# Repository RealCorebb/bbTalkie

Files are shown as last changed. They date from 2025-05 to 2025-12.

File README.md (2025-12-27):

# bbTalkie [English](https://github.com/RealCorebb/bbTalkie/blob/main/README_EN.md "English")



## 不太一样的迷你对讲机

普通对讲机又大又笨，还得按键才能讲话。 有天骑行时，我想——能不能做一款便携、免按键的对讲机？ 于是我 DIY 了一款不太一样的对讲机，使用嵌入式神经网络🧠，能自动检测人声🗣️、识别关键词触发动画，其它对话也能转文字气泡显示，非常好玩。

😄[爱发电](https://afdian.com/a/kuruibb "爱发电")   
🐧QQ 群（仅供交流）：647186542  
🧵[Threads](https://www.threads.net/@coreoobb "@coreoobb") @coreoobb  
▶️ 本期视频(Video): [Youtube](https://youtu.be/v0QcsWsoYbw "Youtube") | [ Bilibili](https://www.bilibili.com/video/BV1qtBBBwEWv " Bilibili")

# 禁止搬运到 Gitee

Designed By Corebb With Love From bbRealm!

# 目录结构：

**CAD** 3D模型、DXF切割图纸  
**PCB** PCB 原理图、Gerber 制板文件、BOM 、坐标文件、EDA工程
**assets** 资源文件，如动画图像、音频、设计文件  
**esp-idf** 软件主程序，使用ESP-IDF V5.4.3版本，烧录到 ESP32 中  
**tests** 开发过程中用到的测试程序  
**tools** 软件部分开发辅助工具，如字体取模、图形转换、音频转换等  

# 如何使用 & FAQ：
需要用ESP32-S3 16MB Flash 8MB PSRAM的版本（只有这个才能用上Octal PSRAM，不然PSRAM速度跟不上会导致ESP-SR这套音频框架卡死）  
建议使用外置天线的版本：ESP32-S3-WROOM-1U-N16R8  
使用ESP-IDF开发环境编译并烧录  

# 参考资料：

开发框架  
[ESP-IDF快速入门](https://docs.espressif.com/projects/esp-idf/zh_CN/v5.4.3/esp32/get-started/index.html)
[ESP-SR](https://docs.espressif.com/projects/esp-sr/zh_CN/latest/esp32/getting_started/readme.html)

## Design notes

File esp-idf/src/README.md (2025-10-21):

#Antenna Test
Overair -55dbm | -80dbm
No.2 -55dbm | -76dbm
     -53dbM | -66dbM

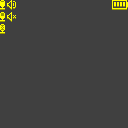
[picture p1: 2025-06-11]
IMG/UI_Concept.png

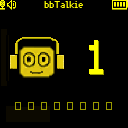
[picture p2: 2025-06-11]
IMG/bbTalkie_IDLE_Concept.gif

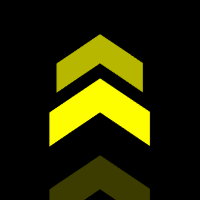
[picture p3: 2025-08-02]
IMG/go_straight.gif

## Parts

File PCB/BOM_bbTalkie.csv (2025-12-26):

Designator | Footprint | Value | Supplier Part | Manufacturer | Comment
C1,C5,C6,C12,C14 | C0603 | 1uF |  |  | 1uF
C2,C7,C8,C10 | C0603 | 0.1uF |  |  | 0.1uF
C3,C4,C9,C11 | C0603 | 10uF |  |  | 10uF
C13 | C0603 | 47uF |  |  | 47uF
C15 | C0603 | 22uF |  |  | 22uF
CN1,CN2 | CONN-SMD_2P-P1.00_SM02B-SRSS-TB-LF-SN |  | C160402 | JST | SM02B-SRSS-TB(LF)(SN)
D1 | SOD-323_L1.8-W1.3-LS2.5-RD |  | C22624 | CJ(江苏长电/长晶) | B5819WS
L1 | IND-SMD_L2.5-W2.0_SWPA252012S | 10uH | C37428 | Sunlord(顺络) | 10uH
L2 | IND-SMD_L2.0-W1.6-B | 1uH | C5832342 | cjiang(长江微电) | 1uH
LED1 | LED-SMD_WS2812B-4020 |  | C965557 | worldsemi | WS2812B-4020
R1,R3 | R0603 | 100K |  |  | 100K
R2 | R0603 | 390K |  |  | 390K
R4,R10,R11 | R0603 | 5.1K |  |  | 5.1K
R5 | R0603 | 10K |  |  | 10K
R6 | R0603 | 1.8K |  |  | 1.8K
R7,R8,R12 | R0603 | 511K |  |  | 511K
R9 | R0603 | 91K |  |  | 91K
SW1 | SW-SMD_TS24CA |  | C393942 | SHOU HAN(首韩) | TS24CA
U1 | WIRELM-SMD_ESP32-S3-WROOM-1 |  | C2913202 | ESPRESSIF(乐鑫) | ESP32-S3-WROOM-1-N16R8
U2 | MIC-SMD_6P-L3.5-W2.7-P0.90-BL |  | C5656610 | TDK InvenSense(应美盛) | ICS-43434
U3 | TQFN-16_L3.0-W3.0-P0.50-BL-EP1.5 |  | C910544 | ADI(亚德诺)/MAXIM(美信) | MAX98357AETE+T
U4 | SOT23-5@1 |  |  |  | FAN5331SX
U5 | SOT-583-8_L2.1-W1.6-P0.50-LS1.6-BL |  | C3235557 | TI(德州仪器) | TPS2116DRLR
U6 | SC-70-6_L2.2-W1.3-P0.65-LS2.1-BR |  | C2149796 | TI(德州仪器) | TPS22919DCKR
U7 | SOT-23-6_L2.9-W1.6-P0.95-LS2.8-BR |  | C82121 | MICRONE(南京微盟) | ME4055AM6G-N
U8 | SOT-583-8_L2.1-W1.2-P0.50-LS1.6-BL |  | C5219190 | TI(德州仪器) | TPS631000DRLR
USB1 | USB-C-SMD_KH-TYPE-C-16P |  | C709357 | kinghelm(金航标) | KH-TYPE-C-16P
X1 | OLED_1.5IN_128X128MONO |  |  |  | OLED_1.5_128X128_MONO

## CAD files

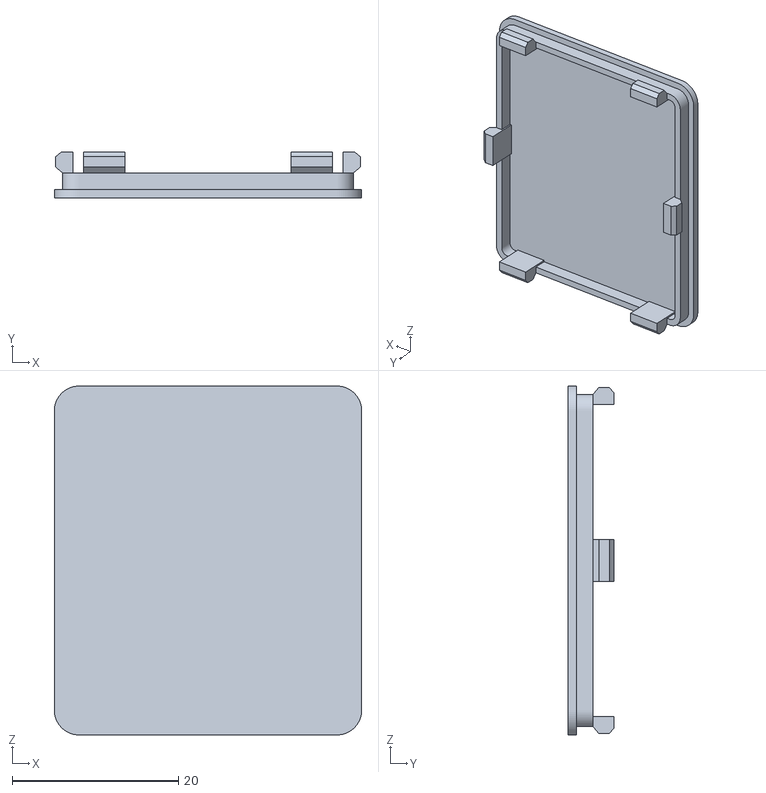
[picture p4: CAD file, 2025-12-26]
CAD/Bottom.stl
37.0 x 5.50 x 42.0

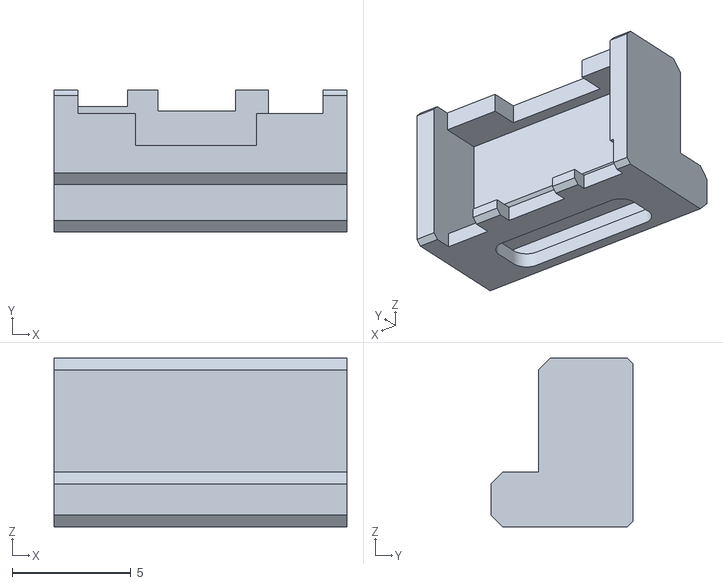
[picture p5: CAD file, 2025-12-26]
CAD/led_case.stl
12.3 x 6.00 x 7.10

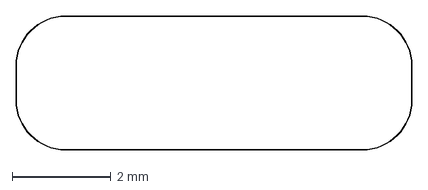
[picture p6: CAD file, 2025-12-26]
CAD/led_pmma.dxf
8.00 x 2.70 mm

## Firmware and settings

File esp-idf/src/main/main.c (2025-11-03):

/*
   This example code is in the Public Domain (or CC0 licensed, at your option.)

   Unless required by applicable law or agreed to in writing, this
   software is distributed on an "AS IS" BASIS, WITHOUT WARRANTIES OR
   CONDITIONS OF ANY KIND, either express or implied.
*/
#include <stdio.h>
#include <stdint.h>
#include <stdlib.h>
#include "freertos/FreeRTOS.h"
#include "freertos/queue.h"
#include "freertos/task.h"
#include "esp_wn_iface.h"
#include "esp_wn_models.h"
#include "esp_vadn_models.h"
#include "esp_afe_sr_models.h"
#include "esp_mn_iface.h"
#include "esp_mn_models.h"
#include "esp_board_init.h"
#include "model_path.h"
#include <math.h> // Add this for sin() function
#include <string.h>
#include "driver/gpio.h"
#include "include/sound.h"
#include "esp_audio_enc.h"
#include "esp_audio_enc_reg.h"
#include "esp_audio_enc_default.h"
#include "esp_audio_dec_default.h"
#include "esp_audio_dec.h"
#include "esp_adpcm_enc.h"
#include "esp_adpcm_dec.h"
#include <sys/socket.h>
#include <netinet/in.h>
#include <arpa/inet.h>

#include "esp_system.h"
#include "esp_now.h"
#include "esp_wifi.h"
#include "esp_timer.h"
#include "esp_event.h"
#include "esp_log.h"
#include "nvs_flash.h"

#include "lwip/err.h"
#include "lwip/sys.h"

#include "freertos/stream_buffer.h"

#include "esp32-spi-ssd1327.h"
#include <inttypes.h>
#include "driver/spi_master.h"
#include "include/images/logo.h"
#include "include/images/battery.h"
#include "include/images/mic.h"
#include "include/images/volume.h"
#include "include/images/home.h"
#include "include/images/custom.h"

#include "include/animation.h"
#include "include/command_map.h"

#include "include/fonts/fusion_pixel.h"
#include "include/fonts/fusion_pixel_30.h"

#include "driver/adc.h"
#include "soc/adc_channel.h"

#include "include/agc.h"
#include "include/led.h"
#include "esp_sleep.h"
#include "driver/rtc_io.h"
#include "iot_button.h"
#include "button_gpio.h"

#define SAMPLE_RATE 16000
#define BIT_DEPTH 16
#define ENCODED_BUF_SIZE 10240
#define PLAY_RING_BUFFER_SIZE 8192
#define PLAY_CHUNK_SIZE 2048
#define ESP_NOW_PACKET_SIZE 512

#define SPI_MOSI_PIN_NUM 14
#define SPI_SCK_PIN_NUM 13
#define SPI_CS_PIN_NUM 10
#define DC_PIN_NUM 12
#define RST_PIN_NUM 11
#define SPI_HOST_TAG SPI2_HOST

#define GPIO_WAKEUP_1 GPIO_NUM_4 // Charger CHRG
#define GPIO_WAKEUP_2 GPIO_NUM_8 // Button
#define GPIO_WAKEUP_3 GPIO_NUM_5 // Charger STDBY

// Button configuration
#define BUTTON_GPIO 8           // Boot button on most ESP32 boards
#define BUTTON_ACTIVE_LEVEL 0   // Active low (pressed = 0)
#define LONG_PRESS_TIME_MS 2000 // 2 seconds for long press

#define PING_MAGIC "PING"
#define PING_MAGIC_LEN 4
#define MAX_MAC_TRACK 9
#define MAC_TIMEOUT_MS 20000
int macCount = 1;
int lastMacCount = 0;
spi_oled_animation_t *anim_currentCommand = NULL;

typedef struct
{
    uint8_t mac[ESP_NOW_ETH_ALEN]; // 6 bytes
    int64_t last_seen_ms;          // Timestamp in ms
    bool valid;
} mac_track_entry_t;


#define ADPCM_FRAME_SIZE 505  // 每帧样本数
#define ADPCM_FRAME_BYTES (ADPCM_FRAME_SIZE * sizeof(int16_t))

// 编码缓冲区结构
typedef struct {
    int16_t buffer[ADPCM_FRAME_SIZE];
    size_t current_samples;  // 当前缓冲区中的样本数
} adpcm_encode_buffer_t;

adpcm_encode_buffer_t encode_buffer;

static mac_track_entry_t mac_track_list[MAX_MAC_TRACK];

const variable_font_t font_10 = {
    .height = 10,
    .widths = font_10_widths,
    .offsets = font_10_offsets,
    .data = font_10_data};

const variable_font_t font_30 = {
    .height = 30,
    .widths = font_30_widths,
    .offsets = font_30_offsets,
    .data = font_30_data};

static esp_afe_sr_iface_t *afe_handle = NULL;
srmodel_list_t *models = NULL;
StreamBufferHandle_t play_stream_buf;
static QueueHandle_t s_recv_queue = NULL;
static uint8_t broadcast_mac[ESP_NOW_ETH_ALEN] = {0xFF, 0xFF, 0xFF, 0xFF, 0xFF, 0xFF}; // Broadcast MAC address (all ones)
volatile bool is_receiving = false;
volatile bool is_speaking = false;
bool isShutdown = false;
bool isMicOff = false;
bool isMute = false;
bool is_command = false;
int state = 0; // 0: idle, 1: speaking, 2: receiving, 3: command
int lastState = -1;
static button_handle_t btn = NULL;
static bool button_initialized = false;
static const char *TAG = "bbTalkie";
spi_device_handle_t oled_dev_handle;
struct spi_ssd1327 spi_ssd1327 = {
    .dc_pin_num = DC_PIN_NUM,
    .rst_pin_num = RST_PIN_NUM,
    .spi_handle = &oled_dev_handle,
};
SemaphoreHandle_t spi_mutex;

// AGC playback
// Initialize AGC
agc_t agc_custom = {
    .current_gain = 1.0f,
    .target_rms = TARGET_RMS,
    .attack_rate = AGC_ATTACK,
    .release_rate = AGC_RELEASE
};

// Calculate RMS of audio buffer
float calculate_rms(int16_t* buffer, size_t samples) {
    float sum = 0.0f;
    for (size_t i = 0; i < samples; i++) {
        float sample = (float)buffer[i];
        sum += sample * sample;
    }
    return sqrtf(sum / samples);
}

// Apply AGC to audio buffer
void apply_agc(int16_t* buffer, size_t samples, agc_t* agc) {
    // Calculate current RMS level
    float current_rms = calculate_rms(buffer, samples);
    
    // Avoid division by zero
    if (current_rms < 1.0f) current_rms = 1.0f;
    
    // Calculate desired gain
    float desired_gain = agc->target_rms / current_rms;
    
    // Apply attack/release smoothing
    float rate = (desired_gain < agc->current_gain) ? agc->attack_rate : agc->release_rate;
    agc->current_gain += rate * (desired_gain - agc->current_gain);
    
    // Clamp gain to reasonable limits
    if (agc->current_gain < MIN_GAIN) agc->current_gain = MIN_GAIN;
    if (agc->current_gain > MAX_GAIN) agc->current_gain = MAX_GAIN;
    
    // Apply gain to all samples
    for (size_t i = 0; i < samples; i++) {
        float sample = (float)buffer[i] * agc->current_gain;
        
        // Clamp to prevent overflow
        if (sample > 32767.0f) sample = 32767.0f;
        if (sample < -32768.0f) sample = -32768.0f;
        
        buffer[i] = (int16_t)sample;
    }
}

// Structure to hold received data
typedef struct
{
    uint8_t data[ESP_NOW_MAX_DATA_LEN_V2];
    size_t data_len;
} esp_now_recv_data_t;

// Callback function called when data is sent
static void esp_now_send_cb(const uint8_t *mac_addr, esp_now_send_status_t status)
{
    if (status == ESP_NOW_SEND_SUCCESS)
    {
        // ESP_LOGI(TAG, "ESP-NOW data sent successfully");
    }
    else
    {
        ESP_LOGW(TAG, "ESP-NOW data send failed");
    }
}

void send_data_esp_now(const uint8_t *data, size_t len)
{
    size_t offset = 0;

    while (offset < len)
    {
        size_t chunk_size = len - offset > ESP_NOW_PACKET_SIZE ? ESP_NOW_PACKET_SIZE : len - offset;

        esp_err_t ret = esp_now_send(broadcast_mac, data + offset, chunk_size);
        if (ret != ESP_OK)
        {
            ESP_LOGE(TAG, "ESP-NOW send failed at offset %zu: %s", offset, esp_err_to_name(ret));
        }
        else
        {
            // ESP_LOGI(TAG, "Sent %zu bytes of data via ESP-NOW (offset %zu)", chunk_size, offset);
        }

        offset += chunk_size;
        vTaskDelay(pdMS_TO_TICKS(16));
    }
}

// Get received data (non-blocking)
bool get_esp_now_data(esp_now_recv_data_t *recv_data)
{
    if (s_recv_queue == NULL || recv_data == NULL)
    {
        return false;
    }

    return (xQueueReceive(s_recv_queue, recv_data, 0) == pdTRUE);
}

// Fade in drawText
void fade_in_drawCount(void *arg)
{
    const char *input_text = (const char *)arg;
    if (input_text == NULL || strlen(input_text) == 0)
    {
        printf("Invalid text\n");
        vTaskDelete(NULL);
        return;
    }
    for (int i = 0; i < 15; i++)
    {
        if (state == 0)
        {
            spi_oled_drawText(&spi_ssd1327, 86, 46, &font_30, i / 2, input_text, 0);
            spi_oled_drawText(&spi_ssd1327, 85, 45, &font_30, i, input_text, 0);
        }
        else
        {
            vTaskDelete(NULL);
        }
        vTaskDelay(pdMS_TO_TICKS(1000 / 15));
    }
    vTaskDelete(NULL);
}

// Animation task function
static void animation_task(void *pvParameters)
{
    spi_oled_animation_t *anim = (spi_oled_animation_t *)pvParameters;
    if (anim == NULL)
    {
        // Handle error - invalid key
        printf("Invalid animation parameters\n");
        vTaskDelete(NULL);
        return;
    }
    int current_frame = 0;
    uint8_t bytes_per_row = (anim->width + 1) / 2; // 4bpp packing
    while ((anim->stop_frame == -1 && anim->is_playing == true) ||
           (anim->stop_frame != -1 && (anim->is_playing == true || current_frame != anim->stop_frame)))
    {
        if (anim->stop_frame == -1 && anim->is_playing == false)
        {
            break;
        }
        if (anim->stop_frame != -1 && anim->is_playing == false && (state == 3 || current_frame == anim->stop_frame))
            break; // Force break when state is 3
        // Calculate frame data offset
        const uint8_t *frame_data = anim->animation_data +
                                    (current_frame * anim->height * bytes_per_row);

        // Lock SPI access
        xSemaphoreTake(spi_mutex, portMAX_DELAY);

        // Draw current frame
        spi_oled_drawImage(&spi_ssd1327,
                           anim->x, anim->y,
                           anim->width, anim->height,
                           frame_data, SSD1327_GS_15);

        // Release SPI access
        xSemaphoreGive(spi_mutex);

        // Move to next frame
        if (anim->reverse == true)
        {
            current_frame--;
        }
        else
            current_frame++;
        if (current_frame >= anim->frame_count)
        {
            current_frame = 0;
        }
        else if (current_frame < 0)
        {
            current_frame = anim->frame_count - 1;
        }

        vTaskDelay(pdMS_TO_TICKS(anim->frame_delay_ms));
    }
    vTaskDelete(NULL);
}

void stopAllAnimation()
{
    anim_waveBar.is_playing = false;
    anim.is_playing = false;
    anim_speaking.is_playing = false;
    anim_receiving.is_playing = false;
    anim_idleWaveBar.is_playing = false;
    anim_idleBar.is_playing = false;
    anim_podcast.is_playing = false;
    anim_speaker.is_playing = false;
     if (anim_currentCommand != NULL)
                anim_currentCommand->is_playing = false;
}

void bubble_text_task(void *arg)
{
    const char *input_text = (const char *)arg;
    if (input_text == NULL || strlen(input_text) == 0)
    {
        printf("Invalid text for bubble task\n");
        vTaskDelete(NULL);
        return;
    }

    // Create a local copy to prevent corruption
    char text[64]; // Adjust size as needed
    strncpy(text, input_text, sizeof(text) - 1);
    text[sizeof(text) - 1] = '\0';

    for (int i = -6; i < 0; i++)
    {
        spi_oled_drawImage(&spi_ssd1327, 17, i, 93, 11, (const uint8_t *)text_bubble, SSD1327_GS_15);
        spi_oled_drawText(&spi_ssd1327, 18, i, &font_10, SSD1327_GS_1, text, 86);
        vTaskDelay(pdMS_TO_TICKS(1000 / 15));
    }
    vTaskDelete(NULL);
}

// ESP-NOW receive callback
static void esp_now_recv_cb(const esp_now_recv_info_t *recv_info, const uint8_t *data, int data_len)
{
    if (recv_info == NULL || data == NULL || data_len <= 0)
    {
        return;
    }

    // Log reception
    
    ESP_ERROR_CHECK(esp_wifi_connectionless_module_set_wake_interval(0));
    ESP_LOGI(TAG, "Received %d bytes, RSSI: %d dBm", data_len, recv_info->rx_ctrl->rssi);

    if (data_len == PING_MAGIC_LEN && memcmp(data, PING_MAGIC, PING_MAGIC_LEN) == 0) // PING MSG
    {
        int64_t now = esp_timer_get_time() / 1000; // ms
        bool found = false;
        ESP_LOGI(TAG, "Received PING from %02x:%02x:%02x:%02x:%02x:%02x",
                 recv_info->src_addr[0], recv_info->src_addr[1],
                 recv_info->src_addr[2], recv_info->src_addr[3],
                 recv_info->src_addr[4], recv_info->src_addr[5]);
        for (int i = 0; i < MAX_MAC_TRACK; ++i)
        {
            if (mac_track_list[i].valid &&
                memcmp(mac_track_list[i].mac, recv_info->src_addr, ESP_NOW_ETH_ALEN) == 0)
            {
                mac_track_list[i].last_seen_ms = now;
                found = true;
                break;
            }
        }

        if (!found)
        {
            for (int i = 0; i < MAX_MAC_TRACK; ++i)
            {
                if (!mac_track_list[i].valid)
                {
                    memcpy(mac_track_list[i].mac, recv_info->src_addr, ESP_NOW_ETH_ALEN);
                    mac_track_list[i].last_seen_ms = now;
                    mac_track_list[i].valid = true;
                    ESP_LOGI(TAG, "Added MAC");
                    macCount += 1;
                    break;
                }
            }
        }
    }
    // CMD: prefix handling
    else if (data_len >= 4 && memcmp(data, "CMD:", 4) == 0)
    {
        if (data_len >= 5)
        {
            // Extract the command parameter after "CMD:"
            char cmd_param[32]; // Adjust size as needed
            int param_len = data_len - 4;
            if (param_len >= sizeof(cmd_param))
            {
                param_len = sizeof(cmd_param) - 1;
            }
            memcpy(cmd_param, data + 4, param_len);
            cmd_param[param_len] = '\0';

            // Convert to integer and handle animation
            int cmd_value = atoi(cmd_param);
            ESP_LOGI(TAG, "Processed CMD: %d", cmd_value);

            // Handle animation for received command
            printf("Playing animation for received command_id: %d\n", cmd_value);
            if (anim_currentCommand != NULL)
                anim_currentCommand->is_playing = false;
            anim_currentCommand = get_animation_by_key(cmd_value);
            lastState = -1;
            is_command = true;
        }
    }
    // MSG: prefix handling
    else if (data_len >= 4 && memcmp(data, "MSG:", 4) == 0)
    {
        if (data_len >= 5)
        {
            // Extract the message content after "MSG:"
            char msg_content[ESP_NOW_MAX_DATA_LEN_V2]; // Adjust size as needed
            int content_len = data_len - 4;
            if (content_len >= sizeof(msg_content))
            {
                content_len = sizeof(msg_content) - 1;
            }
            memcpy(msg_content, data + 4, content_len);
            msg_content[content_len] = '\0';
            ESP_LOGI(TAG, "Processed MSG: %s", msg_content);

            // Create bubble text task for received message
            char *msg_copy = malloc(strlen(msg_content) + 1);
            if (msg_copy != NULL)
            {
                strcpy(msg_copy, msg_content);
                xTaskCreate(bubble_text_task, "bubbleText", 4096, msg_copy, 5, NULL);
                ESP_LOGI(TAG, "Created bubble_text_task for received message: %s", msg_content);
            }
            else
            {
                ESP_LOGE(TAG, "Failed to allocate memory for bubble text message");
            }
        }
    }
    // Others MSG, Store in queue if available
    else if (s_recv_queue != NULL)
    {
        is_receiving = true;
        esp_now_recv_data_t recv_data;

        // Copy data (with size check)
        size_t copy_len = (data_len > ESP_NOW_MAX_DATA_LEN_V2) ? ESP_NOW_MAX_DATA_LEN_V2 : data_len;
        memcpy(recv_data.data, data, copy_len);
        recv_data.data_len = copy_len;

        // Send to queue, don't block if full
        xQueueSend(s_recv_queue, &recv_data, 0);
    }
}

// Initialize ESP-NOW
bool init_esp_now()
{
    // Initialize WiFi
    ESP_ERROR_CHECK(esp_netif_init());
    ESP_ERROR_CHECK(esp_event_loop_create_default());
    wifi_init_config_t cfg = WIFI_INIT_CONFIG_DEFAULT();
    esp_err_t ret = esp_wifi_init(&cfg);
    if (ret != ESP_OK)
    {
        ESP_LOGE(TAG, "WiFi init failed: %s", esp_err_to_name(ret));
        return false;
    }
    
    // Set WiFi mode
    ret = esp_wifi_set_mode(WIFI_MODE_STA);
    if (ret != ESP_OK)
    {
        ESP_LOGE(TAG, "WiFi set mode failed: %s", esp_err_to_name(ret));
        return false;
    }

    // Start WiFi
    ret = esp_wifi_start();
    if (ret != ESP_OK)
    {
        ESP_LOGE(TAG, "WiFi start failed: %s", esp_err_to_name(ret));
        return false;
    }

    // Initialize ESP-NOW
    ret = esp_now_init();
    if (ret != ESP_OK)
    {
        ESP_LOGE(TAG, "ESP-NOW init failed: %s", esp_err_to_name(ret));
        return false;
    }

    // Register callbacks
    esp_now_register_send_cb(esp_now_send_cb);
    esp_now_register_recv_cb(esp_now_recv_cb);

    // Add broadcast peer
    esp_now_peer_info_t peer_info = {0};
    memcpy(peer_info.peer_addr, broadcast_mac, ESP_NOW_ETH_ALEN);
    peer_info.channel = 0; // Use the same channel as AP
    peer_info.encrypt = false;

    ret = esp_now_add_peer(&peer_info);
    if (ret != ESP_OK && ret != ESP_ERR_ESPNOW_EXIST)
    {
        ESP_LOGE(TAG, "Add broadcast peer failed: %s", esp_err_to_name(ret));
        return false;
    }

    ESP_ERROR_CHECK(esp_now_set_wake_window(25));
    ESP_ERROR_CHECK(esp_wifi_connectionless_module_set_wake_interval(100));

    // Create receive queue (holds up to 10 messages)
    s_recv_queue = xQueueCreate(10, sizeof(esp_now_recv_data_t));

    ESP_LOGI(TAG, "ESP-NOW initialized successfully");
    return true;
}
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
void app_main()
{
    // Check which GPIO caused the wakeup (if any)
    ws2812_init();
    uint64_t wakeup_pin_mask = esp_sleep_get_ext1_wakeup_status();
    
    // Reset critical flags first
    isShutdown = false;
    
    // Initialize NVS
    esp_err_t ret = nvs_flash_init();
    if (ret == ESP_ERR_NVS_NO_FREE_PAGES || ret == ESP_ERR_NVS_NEW_VERSION_FOUND)
    {
        ESP_ERROR_CHECK(nvs_flash_erase());
        ret = nvs_flash_init();
    }
    ESP_ERROR_CHECK(ret);

    init_esp_now();

    ESP_ERROR_CHECK(esp_board_init(SAMPLE_RATE, 1, BIT_DEPTH));

    models = esp_srmodel_init("model");
    afe_config_t *afe_config = afe_config_init(esp_get_input_format(), models, AFE_TYPE_SR, AFE_MODE_LOW_COST);
    
    afe_config->vad_min_noise_ms = 800;
    afe_config->vad_min_speech_ms = 128;
    afe_config->vad_mode = VAD_MODE_1;  // The larger the mode, the higher the speech trigger probability.
    afe_config->afe_linear_gain = 2.0;

    afe_handle = esp_afe_handle_from_config(afe_config);
    esp_afe_sr_data_t *afe_data = afe_handle->create_from_config(afe_config);
    afe_config_free(afe_config);

    printf("afe_linear_gain:%f\n", afe_config->afe_linear_gain);
    printf("agc_init:%d, agc_mode:%d, agc_compression_gain_db:%d, agc_target_level_dbfs:%d\n", 
           afe_config->agc_init, afe_config->agc_mode, afe_config->agc_compression_gain_db, afe_config->agc_target_level_dbfs);

    // Configure output GPIOs first
    gpio_config_t io_conf_3 = {
        .pin_bit_mask = (1ULL << GPIO_NUM_3),
        .mode = GPIO_MODE_OUTPUT,
        .pull_up_en = GPIO_PULLUP_DISABLE,
        .pull_down_en = GPIO_PULLDOWN_DISABLE,
        .intr_type = GPIO_INTR_DISABLE,
    };
    gpio_config(&io_conf_3);

    gpio_config_t io_conf_9 = {
        .pin_bit_mask = (1ULL << GPIO_NUM_9),
        .mode = GPIO_MODE_OUTPUT,
        .pull_up_en = GPIO_PULLUP_DISABLE,
        .pull_down_en = GPIO_PULLDOWN_DISABLE,
        .intr_type = GPIO_INTR_DISABLE,
    };
    gpio_config(&io_conf_9);

    gpio_set_level(GPIO_NUM_3, 1);
    gpio_set_level(GPIO_NUM_9, 1);

    // Configure wake up GPIOs
    gpio_config_t io_conf = {
        .pin_bit_mask = (1ULL << GPIO_WAKEUP_1) | (1ULL << GPIO_WAKEUP_2) | (1ULL << GPIO_WAKEUP_3),
        .mode = GPIO_MODE_INPUT,
        .pull_up_en = GPIO_PULLUP_ENABLE,
        .pull_down_en = GPIO_PULLDOWN_DISABLE,
        .intr_type = GPIO_INTR_DISABLE};
    gpio_config(&io_conf);

    rtc_gpio_pullup_en(GPIO_WAKEUP_1);
    rtc_gpio_pullup_en(GPIO_WAKEUP_2);
    rtc_gpio_pullup_en(GPIO_WAKEUP_3);

    rtc_gpio_pulldown_dis(GPIO_WAKEUP_1);
    rtc_gpio_pulldown_dis(GPIO_WAKEUP_2);
    rtc_gpio_pulldown_dis(GPIO_WAKEUP_3);

    esp_sleep_enable_ext1_wakeup((1ULL << GPIO_WAKEUP_1) | (1ULL << GPIO_WAKEUP_2) | (1ULL << GPIO_WAKEUP_3), ESP_EXT1_WAKEUP_ANY_LOW);

    // Handle charging wake-up
    if ((wakeup_pin_mask & (1ULL << GPIO_WAKEUP_1)) || (wakeup_pin_mask & (1ULL << GPIO_WAKEUP_3)))
    {
        printf("Wakeup caused by GPIO4 (Charger CHRG) / GPIO5 (Charger STDBY)\n");
        xTaskCreatePinnedToCore(charging_Task, "charging", 4 * 1024, NULL, 5, NULL, 0);
        return;
    }
    
    // Handle button wake-up
    if (wakeup_pin_mask & (1ULL << GPIO_WAKEUP_2))
    {
        printf("Wakeup caused by GPIO8 (Button)\n");
        // Add a small delay to let the GPIO settle after wake-up
        vTaskDelay(pdMS_TO_TICKS(100));
    }

    // Initialize button AFTER all GPIO configurations and wake-up handling
    if (init_button() != ESP_OK) {
        printf("Failed to initialize button, retrying...\n");
        vTaskDelay(pdMS_TO_TICKS(500));
        if (init_button() != ESP_OK) {
            printf("Button initialization failed permanently\n");
            // You might want to handle this error case
        }
    }

    // Continue with the rest of your initialization
    init_audio_stream_buffer();
    xTaskCreatePinnedToCore(oled_task, "oled", 4 * 1024, NULL, 5, NULL, 0);
    xTaskCreatePinnedToCore(boot_sound, "bootSound", 3 * 1024, NULL, 5, NULL, 1);
    xTaskCreatePinnedToCore(&feed_Task, "feed", 8 * 1024, (void *)afe_data, 5, NULL, 0);
    xTaskCreatePinnedToCore(&detect_Task, "detect", 4 * 1024, (void *)afe_data, 5, NULL, 1);
    xTaskCreatePinnedToCore(decode_Task, "decode", 4 * 1024, NULL, 5, NULL, 0);
    xTaskCreatePinnedToCore(i2s_writer_task, "i2sWriter", 4 * 1024, NULL, 5, NULL, 0);
    xTaskCreate(ping_task, "ping", 3 * 1024, NULL, 5, NULL);
    xTaskCreate(led_control_task, "led_control", 3 * 1024, NULL, 5, NULL);
}

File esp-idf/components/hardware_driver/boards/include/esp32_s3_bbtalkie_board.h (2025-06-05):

/**
 * 
 * @copyright Copyright 2021 Espressif Systems (Shanghai) Co. Ltd.
 *
 *      Licensed under the Apache License, Version 2.0 (the "License");
 *      you may not use this file except in compliance with the License.
 *      You may obtain a copy of the License at
 *
 *               http://www.apache.org/licenses/LICENSE-2.0
 *
 *      Unless required by applicable law or agreed to in writing, software
 *      distributed under the License is distributed on an "AS IS" BASIS,
 *      WITHOUT WARRANTIES OR CONDITIONS OF ANY KIND, either express or implied.
 *      See the License for the specific language governing permissions and
 *      limitations under the License.
 */
#pragma once

#include "driver/gpio.h"
#include "esp_idf_version.h"

/**
 * @brief ESP32-S3-EYE I2C GPIO defineation
 * 
 */
#define FUNC_I2C_EN     (0)
#define GPIO_I2C_SCL    (GPIO_NUM_NC)
#define GPIO_I2C_SDA    (GPIO_NUM_NC)

/**
 * @brief ESP32-S3-EYE SDMMC GPIO defination
 * 
 * @note Only avaliable when PMOD connected
 */
#define FUNC_SDMMC_EN   (1)
#define SDMMC_BUS_WIDTH (1)
#define GPIO_SDMMC_CLK  (GPIO_NUM_39)
#define GPIO_SDMMC_CMD  (GPIO_NUM_38)
#define GPIO_SDMMC_D0   (GPIO_NUM_40)
#define GPIO_SDMMC_D1   (GPIO_NUM_4)
#define GPIO_SDMMC_D2   (GPIO_NUM_12)
#define GPIO_SDMMC_D3   (GPIO_NUM_13)
#define GPIO_SDMMC_DET  (GPIO_NUM_NC)

/**
 * @brief ESP32-S3-EYE SDSPI GPIO definationv
 * 
 */
#define FUNC_SDSPI_EN       (0)
#define SDSPI_HOST          (SPI2_HOST)
#define GPIO_SDSPI_CS       (GPIO_NUM_NC)
#define GPIO_SDSPI_SCLK     (GPIO_NUM_NC)
#define GPIO_SDSPI_MISO     (GPIO_NUM_NC)
#define GPIO_SDSPI_MOSI     (GPIO_NUM_NC)

/**
 * @brief ESP32-S3-EYE I2S GPIO defination
 * 
 */
#define FUNC_I2S_EN         (1)
#define GPIO_I2S_LRCK       (GPIO_NUM_1)
#define GPIO_I2S_MCLK       (GPIO_NUM_NC)
#define GPIO_I2S_SCLK       (GPIO_NUM_2)
#define GPIO_I2S_SDIN       (GPIO_NUM_17)
#define GPIO_I2S_DOUT       (GPIO_NUM_18)


/**
 * @brief ESP32-S3-EYE I2S GPIO defination
 * 
 */
#define FUNC_I2S0_EN         (0)
#define GPIO_I2S0_LRCK       (GPIO_NUM_NC)
#define GPIO_I2S0_MCLK       (GPIO_NUM_NC)
#define GPIO_I2S0_SCLK       (GPIO_NUM_NC)
#define GPIO_I2S0_SDIN       (GPIO_NUM_NC)
#define GPIO_I2S0_DOUT       (GPIO_NUM_NC)

/**
 * @brief ESP32-S3-EYE power control IO
 * 
 * @note Some power control pins might not be listed yet
 * 
 */
#define FUNC_PWR_CTRL       (0)
#define GPIO_PWR_CTRL       (GPIO_NUM_NC)
#define GPIO_PWR_ON_LEVEL   (1)

#if ESP_IDF_VERSION >= ESP_IDF_VERSION_VAL(5, 0, 0)

#define I2S_CONFIG_DEFAULT(sample_rate, channel_fmt, bits_per_chan) { \
        .clk_cfg = I2S_STD_CLK_DEFAULT_CONFIG(sample_rate), \
        .slot_cfg = I2S_STD_PHILIPS_SLOT_DEFAULT_CONFIG(bits_per_chan, channel_fmt), \
        .gpio_cfg = { \
            .mclk = GPIO_I2S_MCLK, \
            .bclk = GPIO_I2S_SCLK, \
            .ws   = GPIO_I2S_LRCK, \
            .dout = GPIO_I2S_DOUT, \
            .din  = GPIO_I2S_SDIN, \
            .invert_flags = { \
                .mclk_inv = false, \
                .bclk_inv = false, \
                .ws_inv   = false, \
            }, \
        }, \
    }

#define I2S_TX_CONFIG { \
    .clk_cfg = I2S_STD_CLK_DEFAULT_CONFIG(16000), \
    .slot_cfg = { \
        .data_bit_width = I2S_DATA_BIT_WIDTH_16BIT, \
        .slot_bit_width = I2S_SLOT_BIT_WIDTH_AUTO, \
        .slot_mode = I2S_SLOT_MODE_MONO, \
        .slot_mask = I2S_STD_SLOT_RIGHT, \
        .ws_pol = false, \
        .bit_shift = true, \
        .left_align = false, \
        .big_endian = false, \
    }, \
    .gpio_cfg = { \
        .mclk = GPIO_I2S_MCLK, \
        .bclk = GPIO_I2S_SCLK, \
        .ws   = GPIO_I2S_LRCK, \
        .dout = GPIO_I2S_DOUT, \
        .din  = GPIO_I2S_SDIN, \
        .invert_flags = { \
            .mclk_inv = false, \
            .bclk_inv = false, \
            .ws_inv   = false, \
        }, \
    }, \
}



#else

#define I2S_CONFIG_DEFAULT(sample_rate, channel_fmt, bits_per_chan) { \
    .mode                   = I2S_MODE_MASTER | I2S_MODE_RX, \
    .sample_rate            = 16000, \
    .bits_per_sample        = I2S_BITS_PER_SAMPLE_32BIT, \
    .channel_format         = I2S_CHANNEL_FMT_ONLY_LEFT, \
    .communication_format   = I2S_COMM_FORMAT_STAND_I2S, \
    .intr_alloc_flags       = ESP_INTR_FLAG_LEVEL1, \
    .dma_buf_count          = 6, \
    .dma_buf_len            = 160, \
    .use_apll               = false, \
    .tx_desc_auto_clear     = true, \
    .fixed_mclk             = 0, \
    .mclk_multiple          = I2S_MCLK_MULTIPLE_DEFAULT, \
    .bits_per_chan          = I2S_BITS_PER_CHAN_32BIT, \
}

#endif

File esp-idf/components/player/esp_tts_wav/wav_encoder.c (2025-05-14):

/* ------------------------------------------------------------------
 * Copyright (C) 2009 Martin Storsjo
 *
 * Licensed under the Apache License, Version 2.0 (the "License");
 * you may not use this file except in compliance with the License.
 * You may obtain a copy of the License at
 *
 *      http://www.apache.org/licenses/LICENSE-2.0
 *
 * Unless required by applicable law or agreed to in writing, software
 * distributed under the License is distributed on an "AS IS" BASIS,
 * WITHOUT WARRANTIES OR CONDITIONS OF ANY KIND, either
 * express or implied.
 * See the License for the specific language governing permissions
 * and limitations under the License.
 * -------------------------------------------------------------------
 */

#include "wav_encoder.h"
#include <stdio.h>
#include <string.h>
#include <stdlib.h>
#include <stdint.h>

struct wav_encoder {
	FILE *wav;
	int data_length;

	int sample_rate;
	int bits_per_sample;
	int channels;
};

static void write_string(struct wav_encoder* ww, const char *str) {
	fputc(str[0], ww->wav);
	fputc(str[1], ww->wav);
	fputc(str[2], ww->wav);
	fputc(str[3], ww->wav);
}

static void write_int32(struct wav_encoder* ww, int value) {
	fputc((value >>  0) & 0xff, ww->wav);
	fputc((value >>  8) & 0xff, ww->wav);
	fputc((value >> 16) & 0xff, ww->wav);
	fputc((value >> 24) & 0xff, ww->wav);
}

static void write_int16(struct wav_encoder* ww, int value) {
	fputc((value >> 0) & 0xff, ww->wav);
	fputc((value >> 8) & 0xff, ww->wav);
}

static void write_header(struct wav_encoder* ww, int length) {
	int bytes_per_frame, bytes_per_sec;
	write_string(ww, "RIFF");
	write_int32(ww, 4 + 8 + 16 + 8 + length);
	write_string(ww, "WAVE");

	write_string(ww, "fmt ");
	write_int32(ww, 16);

	bytes_per_frame = ww->bits_per_sample/8*ww->channels;
	bytes_per_sec   = bytes_per_frame*ww->sample_rate;
	write_int16(ww, 1);                   // Format
	write_int16(ww, ww->channels);        // Channels
	write_int32(ww, ww->sample_rate);     // Samplerate
	write_int32(ww, bytes_per_sec);       // Bytes per sec
	write_int16(ww, bytes_per_frame);     // Bytes per frame
	write_int16(ww, ww->bits_per_sample); // Bits per sample

	write_string(ww, "data");
	write_int32(ww, length);
}

void* wav_encoder_open(const char *filename, int sample_rate, int bits_per_sample, int channels) {
	struct wav_encoder* ww = (struct wav_encoder*) malloc(sizeof(*ww));
	memset(ww, 0, sizeof(*ww));
	ww->wav = fopen(filename, "wb");
	if (ww->wav == NULL) {
		free(ww);
		return NULL;
	}
	ww->data_length = 0;
	ww->sample_rate = sample_rate;
	ww->bits_per_sample = bits_per_sample;
	ww->channels = channels;

	write_header(ww, ww->data_length);
	return ww;
}

void wav_encoder_close(void* obj) {
	struct wav_encoder* ww = (struct wav_encoder*) obj;
	if (ww->wav == NULL) {
		free(ww);
		return;
	}
	fseek(ww->wav, 0, SEEK_SET);
	write_header(ww, ww->data_length);
	fclose(ww->wav);
	free(ww);
}

void wav_encoder_run(void* obj, const unsigned char* data, int length) {
	struct wav_encoder* ww = (struct wav_encoder*) obj;
	if (ww->wav == NULL)
		return;
	fwrite(data, length, 1, ww->wav);
	ww->data_length += length;
}

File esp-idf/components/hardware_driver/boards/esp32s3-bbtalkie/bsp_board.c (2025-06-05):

/**
 *
 * @copyright Copyright 2021 Espressif Systems (Shanghai) Co. Ltd.
 *
 *      Licensed under the Apache License, Version 2.0 (the "License");
 *      you may not use this file except in compliance with the License.
 *      You may obtain a copy of the License at
 *
 *               http://www.apache.org/licenses/LICENSE-2.0
 *
 *      Unless required by applicable law or agreed to in writing, software
 *      distributed under the License is distributed on an "AS IS" BASIS,
 *      WITHOUT WARRANTIES OR CONDITIONS OF ANY KIND, either express or implied.
 *      See the License for the specific language governing permissions and
 *      limitations under the License.
 */

#include "string.h"
#include "bsp_board.h"
#if ESP_IDF_VERSION >= ESP_IDF_VERSION_VAL(5, 0, 0)
#include "driver/i2s_std.h"
#include "driver/i2s_tdm.h"
#include "soc/soc_caps.h"
#else
#include "driver/i2s.h"
#endif
#include "driver/gpio.h"
#include "esp_err.h"
#include "esp_log.h"
#include "esp_rom_sys.h"
#include "esp_vfs_fat.h"
#include "sdmmc_cmd.h"
#if ((SOC_SDMMC_HOST_SUPPORTED) && (FUNC_SDMMC_EN))
#include "driver/sdmmc_host.h"
#endif /* ((SOC_SDMMC_HOST_SUPPORTED) && (FUNC_SDMMC_EN)) */

#define GPIO_MUTE_NUM GPIO_NUM_1
#define GPIO_MUTE_LEVEL 1
#define ACK_CHECK_EN 0x1 /*!< I2C master will check ack from slave*/
#define ADC_I2S_CHANNEL 2
static sdmmc_card_t *card;
static const char *TAG = "board";
static int s_play_sample_rate = 16000;
static int s_play_channel_format = 1;
static int s_bits_per_chan = 16;

#if ESP_IDF_VERSION >= ESP_IDF_VERSION_VAL(5, 0, 0)
static i2s_chan_handle_t rx_handle = NULL; // I2S rx channel handler
static i2s_chan_handle_t tx_handle = NULL; // I2S rx channel handler
#endif

static esp_err_t bsp_i2s_init(i2s_port_t i2s_num, uint32_t sample_rate, int channel_format, int bits_per_chan)
{
    esp_err_t ret_val = ESP_OK;
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

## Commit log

2025-05-14 ready esp-idf for esp-sr and display
    [partitions.csv, partitions_esp32.csv]
2025-05-24 Fix esp-now power saving
    [main.c]
2025-06-11 fix the draw text function with new font generator
    [esp32-spi-ssd1327.c, main.c]
2025-06-12 fix multi animation task
    [main.c]
2025-08-04 add reverse and stop_frame on animation
    [main.c]
2025-08-12 Button function
2025-08-25 charging large icon / wake up by GPIO5
2025-08-26 Fix go back home
    [main.c]
2025-10-31 use buffer to match adpcm encoder length
